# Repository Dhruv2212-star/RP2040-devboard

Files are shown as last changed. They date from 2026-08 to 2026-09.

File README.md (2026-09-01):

# RP2040 based devboard. 
**why did i make this board??**  
hmmmm.. well one day i realised that i have made many projects wit devboard but i have never made my own devboard.  
this was it! so this was a golden project opportunity for me to challenge myself to make something.  
i went and search some tutorials on how devboards worked and how to make them.  
Out of all of the possible devboards out there. one particular board caught my eye, it was the **RP2040** Devboard because it was reallllyy easy to make and really functional and powerful because of it's storage capacity and the no. of GPIO pins it had.  

**Now let me explain to you how i built this devboard :)**  
for a Devboard to work you need to have the basic idea of the chip architecture, with our *RP2040* chip, it uses 3.3v for the main power pins but uses 1.1v for the logic pins and fortunately for our chip it has a built in voltage control which reduces the voltage to 1.1v so no need of extra components  

**decoupling capacitors**- we are using 100nF capacitors per each power pin (IOVDD) and 1uF capacitors for VREG_IN and VREG_OUT each and 2 100nF capacitors for DVDD pin, 100nF capacitor for ADC_AVDD and 100nF for USB VDD  

**Flash storage-** for storing our code in the devboard we are using W25Q128JVS chip for this function, we are going to use QSPI pins for this connection  

**Crystal oscillator**- for this build the data sheet recommends 12Mhz crystal, and in our board we are using   
ABLS-12.000MHZ-B4-T for this  

**GPIO pin extensions**- using 1x20 connectors, we extend it to connectors where we can utilize them.  

# BOM ( Bill of materials)  
## Bill of Materials (BOM)

| Reference | Qty | Value / Part | Footprint | Purchase |
| --- | --: | --- | --- | --- |
| C1, C2 | 2 | 10 µF | `C_0603_1608Metric` | [Link](https://amzn.in/d/0bsal2JG) |
| C3, C4, C5, C9–C15 |  10 | 100 nF | `C_0402_1005Metric` | [Link](https://amzn.in/d/0h4zQ3Lf) |
| C6, C7 | 2 | 1 µF | `C_0402_1005Metric` | [Link](https://amzn.in/d/0exjZiSL) |
| C8 | 1 | 100 nF | `C_0402_1005Metric` | [Link](https://amzn.in/d/0hHEodPN) |
| C16, C17 | 2 | 27 pF | `C_0402_1005Metric` | [Link](https://amzn.in/d/0bekUa1Y) |
| D1 | 1 | LED | `LED_0603_1608Metric` | [Link](https://amzn.in/d/0jdhjUcx) |
| J1 | 1 | USB-C Receptacle USB2.0 16P | `USB_C_Receptacle_GCT_USB4105-xx-A_16P` | [Link](https://amzn.in/d/03EJbP2P) |
| J2 | 1 | 1×2 Pin Header | `PinHeader_1x02_P2.54mm_Vertical` | Cut from 1×40 header |
| J3 | 1 | 1×4 Pin Header | `PinHeader_1x04_P2.54mm_Vertical` | Cut from 1×40 header |
| J4, J5 | 2 | 1×20 Pin Header | `PinHeader_1x20_P2.54mm_Vertical` | [Link](https://amzn.in/d/06pAoX1t) |
| R1, R2 | 2 | 5.1 kΩ | `R_0603_1608Metric` | [Link](https://amzn.in/d/05xfBy6B) |
| R3, R9 | 2 | 10 kΩ | `R_0402_1005Metric` | [Link](https://amzn.in/d/02u6eVpk) |
| R4, R5 | 2 | 27.4 Ω | `R_0603_1608Metric` | [Link](https://amzn.in/d/07J2YWcO) |
| R6, R7, R8 | 3 | 1 kΩ | `R_0603_1608Metric` | [Link](https://amzn.in/d/02u6eVpk) |
| SW1 | 1 | RESET — TL3301AF160QG | `SW_Push_1P1T_NO` | [Link](https://www.digikey.in/short/r89qvhmn) |
| U1 | 1 | NCP1117-3.3 | `TO-252-2` | [Link](https://www.digikey.in/short/ff3dmq3j) |
| U2 | 1 | RP2040 | `QFN-56-1EP_7x7mm` | [Link](https://amzn.in/d/011fsK23) |
| U3 | 1 | W25Q128JVS | `SOIC-8_5.3x5.3mm_P1.27mm` | [Link](https://www.digikey.in/short/zzb4v2bb) |
| Y1 | 1 | Crystal | `Crystal_SMD_HC49-SD` | [Link](https://www.digikey.in/short/9m893pn7) |

# Final schematic look: 



# PCB tracing pics on KIcad  





# Acutual PCB preview 

Thumbnail  

# 3D model view in Kicad 



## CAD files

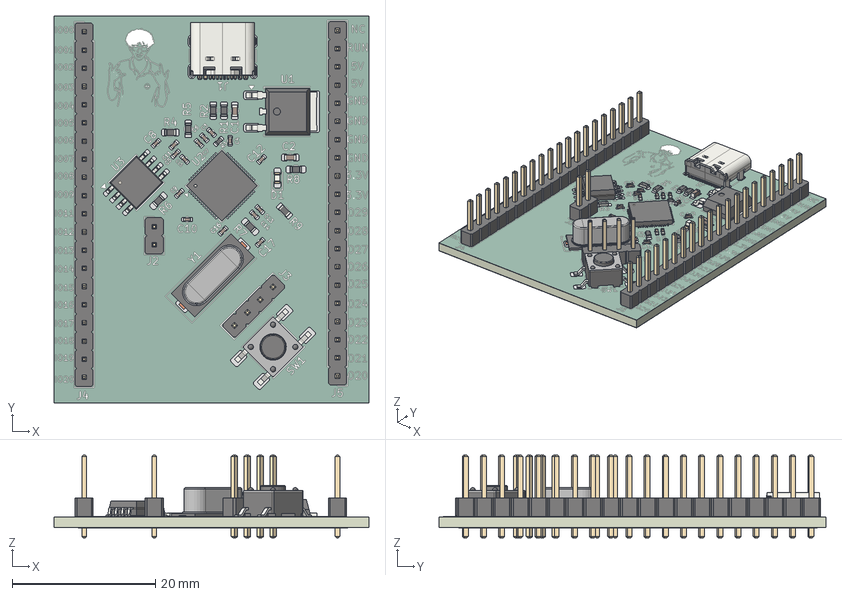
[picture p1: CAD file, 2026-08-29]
3D model/3D Model of PCB.step
44.0 x 54.0 x 11.5 mm
C_0402_1005Metric x 15
SOIC-8_5.3x5.3mm_P1.27mm
R_0603_1608Metric x 8
R_0402_1005Metric
QFN-56-1EP_7x7mm_P0.4mm_EP3.2x3.2mm
LED_0603_1608Metric
932d09b3-9c39-11ed-93f0-dde97e994e83_part
932d09b4-9c39-11ed-93f0-dde97e994e83_part
932d09b5-9c39-11ed-93f0-dde97e994e83_part
Crystal_SMD_HC49-SD
USB_C_Receptacle_16P_TopMnt_Horizontal_GCT_USB4105-xx-A
PinHeader_1x20_P254mm_Vertical x 2
C_0603_1608Metric x 2
PinHeader_1x04_P254mm_Vertical
PinHeader_1x02_P254mm_Vertical
SW_Push_1P1T_NO_E-Switch_TL3301NxxxxxG
RP2040 Devboard_copper
RP2040 Devboard_pad
RP2040 Devboard_via
RP2040 Devboard_silkscreen
RP2040 Devboard_soldermask x 2
RP2040 Devboard_PCB

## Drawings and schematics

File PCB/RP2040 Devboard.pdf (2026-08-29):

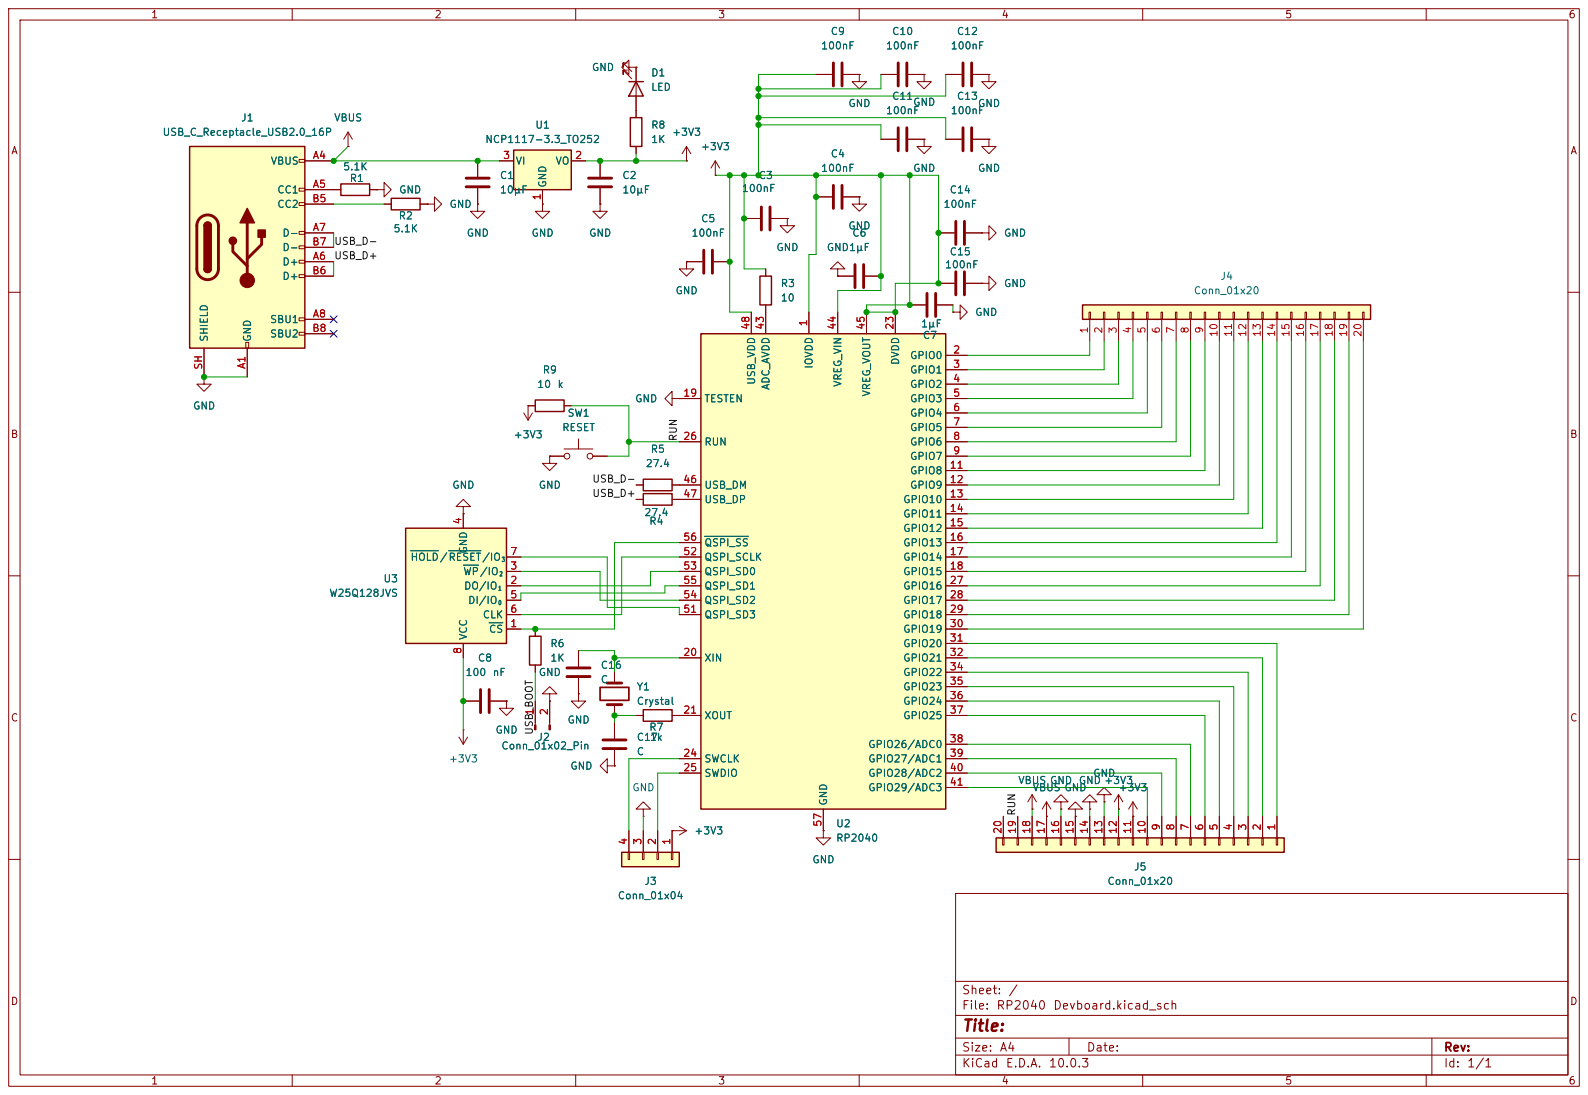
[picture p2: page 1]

Size: A4 | Rev:
KiCad E.D.A. 10.0.3 | Id: 1/1

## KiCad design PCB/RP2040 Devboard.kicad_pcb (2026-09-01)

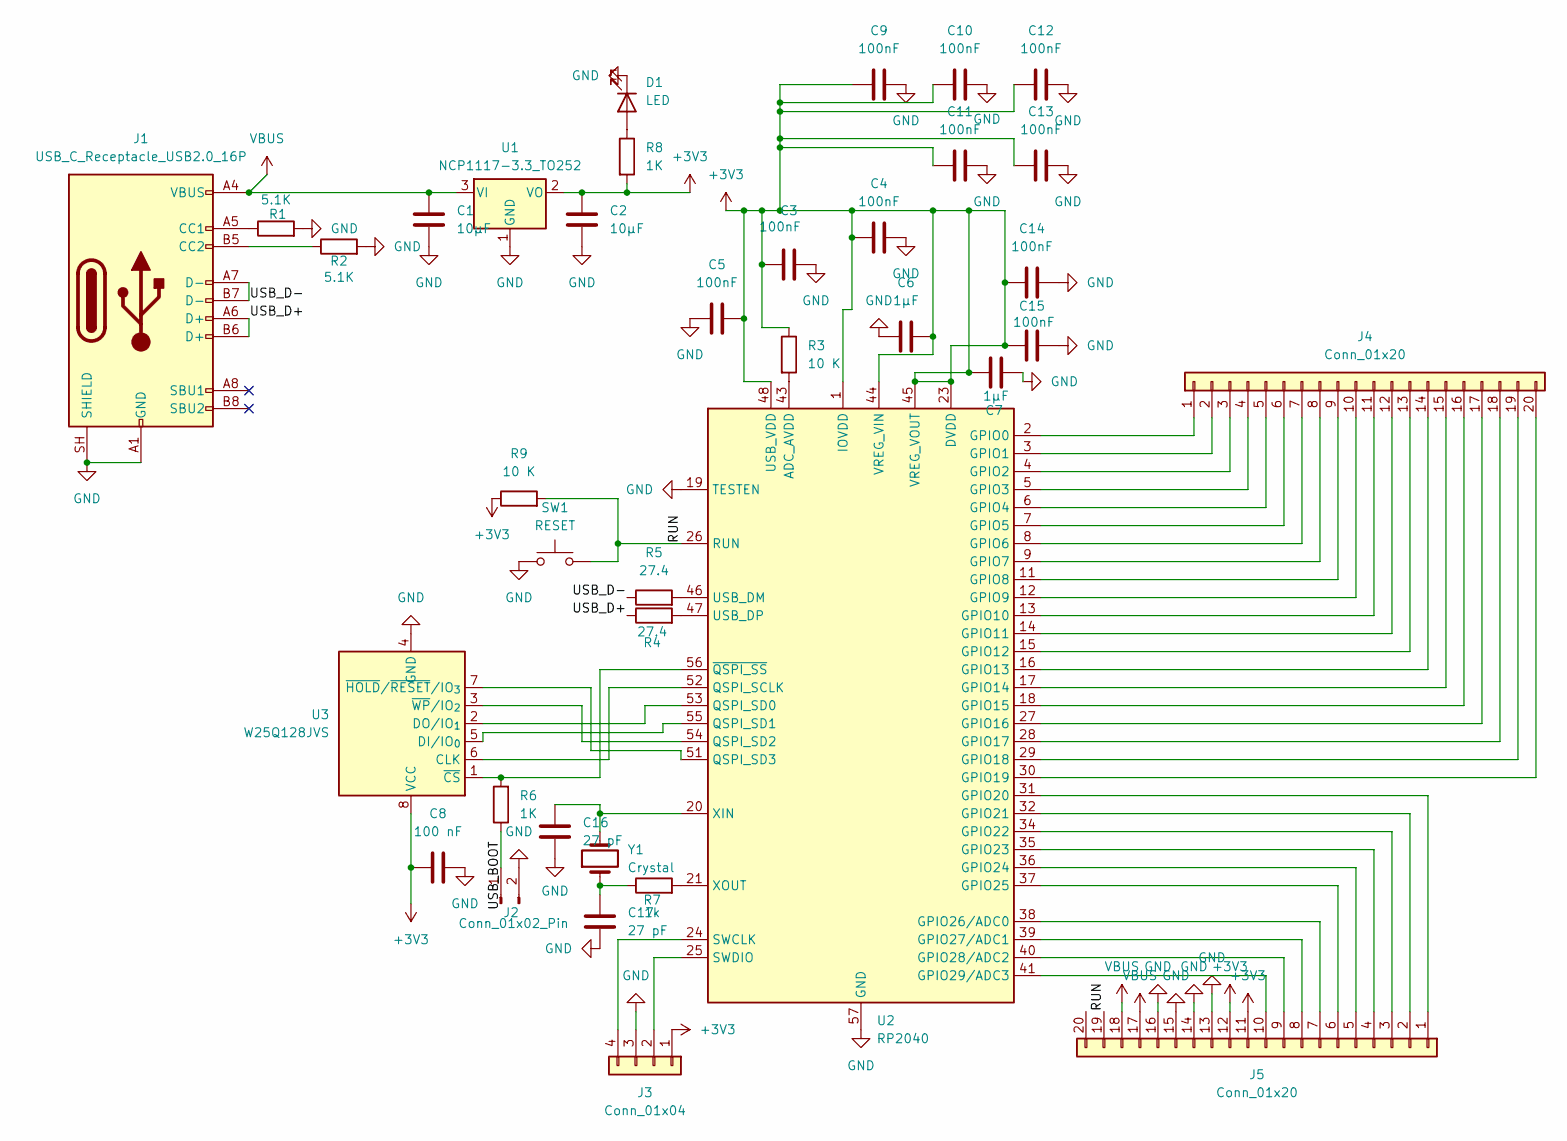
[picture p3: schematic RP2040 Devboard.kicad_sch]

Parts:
C1, C2: 10μF; C_0603_1608Metric
C3, C4, C5, C9, C10, C11, C12, C13, C14, C15: 100nF; C_0402_1005Metric
C6, C7: 1µF; C_0402_1005Metric
C8: 100 nF; C_0402_1005Metric
C16, C17: 27 pF; C_0402_1005Metric
D1: LED; LED_0603_1608Metric_Pad1.05x0.95mm_HandSolder
J1: USB_C_Receptacle_USB2.0_16P; USB_C_Receptacle_GCT_USB4105-xx-A_16P_TopMnt_Horizontal
J2: Conn_01x02_Pin; PinHeader_1x02_P2.54mm_Vertical
J3: Conn_01x04; PinHeader_1x04_P2.54mm_Vertical
J4, J5: Conn_01x20; PinHeader_1x20_P2.54mm_Vertical
R1, R2: 5.1K; R_0603_1608Metric
R3: 10 K; R_0402_1005Metric
R4, R5: 27.4; R_0603_1608Metric
R6, R8: 1K; R_0603_1608Metric_Pad0.98x0.95mm_HandSolder
R7: 1k; R_0603_1608Metric_Pad0.98x0.95mm_HandSolder
R9: 10 K; R_0603_1608Metric
SW1: RESET; SW_Push_1P1T_NO_E-Switch_TL3301NxxxxxG
U1: NCP1117-3.3_TO252; TO-252-2
U2: RP2040; QFN-56-1EP_7x7mm_P0.4mm_EP3.2x3.2mm
U3: W25Q128JVS; SOIC-8_5.3x5.3mm_P1.27mm
Y1: Crystal; Crystal_SMD_HC49-SD

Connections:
+3V3: C2.1, C3.1, C4.2, C5.2, C6.1, C7.2, C8.1, C9.1, C10.1, C11.1, C12.1, C13.1, C14.1, C15.1, J3.1, J5.11, J5.12, R3.1, R8.2, R9.1, U1.2 (VO), U2.1 (IOVDD), U2.10 (IOVDD), U2.22 (IOVDD), U2.23 (DVDD), U2.33 (IOVDD), U2.42 (IOVDD), U2.44 (VREG_VIN), U2.45 (VREG_VOUT), U2.48 (USB_VDD), U2.49 (IOVDD), U2.50 (DVDD), U3.8 (VCC)
/RUN: J5.19, R9.2, SW1.2, U2.26 (RUN)
/USB_BOOT: J2.1, R6.1
/USB_D+: J1.A6 (D+), J1.B6 (D+), R4.1
/USB_D-: J1.A7 (D-), J1.B7 (D-), R5.1
GND: C1.2, C2.2, C3.2, C4.1, C5.1, C6.2, C7.1, C8.2, C9.2, C10.2, C11.2, C12.2, C13.2, C14.2, C15.2, C16.2, C17.2, D1.1 (K), J1.A1 (GND), J1.A12 (GND), J1.B1 (GND), J1.B12 (GND), J1.SH (SHIELD), J2.2, J3.3, J5.13, J5.14, J5.15, J5.16, R1.2, R2.2, SW1.1, U1.1 (GND), U2.19 (TESTEN), U2.57 (GND), U3.4 (GND)
unnamed: C17.1, R7.1, Y1.1
unnamed: D1.2 (A), R8.1
unnamed: J1.A5 (CC1), R1.1
unnamed: J1.B5 (CC2), R2.1
unnamed: J3.2, U2.25 (SWDIO)
unnamed: J3.4, U2.24 (SWCLK)
unnamed: J4.1, U2.2 (GPIO0)
unnamed: J4.2, U2.3 (GPIO1)
unnamed: J4.3, U2.4 (GPIO2)
unnamed: J4.4, U2.5 (GPIO3)
unnamed: J4.5, U2.6 (GPIO4)
unnamed: J4.6, U2.7 (GPIO5)
unnamed: J4.7, U2.8 (GPIO6)
unnamed: J4.8, U2.9 (GPIO7)
unnamed: J4.9, U2.11 (GPIO8)
unnamed: J4.10, U2.12 (GPIO9)
unnamed: J4.11, U2.13 (GPIO10)
unnamed: J4.12, U2.14 (GPIO11)
unnamed: J4.13, U2.15 (GPIO12)
unnamed: J4.14, U2.16 (GPIO13)
unnamed: J4.15, U2.17 (GPIO14)
unnamed: J4.16, U2.18 (GPIO15)
unnamed: J4.17, U2.27 (GPIO16)
unnamed: J4.18, U2.28 (GPIO17)
unnamed: J4.19, U2.29 (GPIO18)
unnamed: J4.20, U2.30 (GPIO19)
unnamed: J5.1, U2.31 (GPIO20)
unnamed: J5.2, U2.32 (GPIO21)
unnamed: J5.3, U2.34 (GPIO22)
unnamed: J5.4, U2.35 (GPIO23)
unnamed: J5.5, U2.36 (GPIO24)
unnamed: J5.6, U2.37 (GPIO25)
unnamed: J5.7, U2.38 (GPIO26/ADC0)
unnamed: J5.8, U2.39 (GPIO27/ADC1)
unnamed: J5.9, U2.40 (GPIO28/ADC2)
unnamed: J5.10, U2.41 (GPIO29/ADC3)
unnamed: R3.2, U2.43 (ADC_AVDD)
unnamed: U2.52 (QSPI_SCLK), U3.6 (CLK)
unnamed: U2.53 (QSPI_SD0), U3.2 (DO/IO_{1})
unnamed: U2.55 (QSPI_SD1), U3.5 (DI/IO_{0})
unnamed: U2.54 (QSPI_SD2), U3.3 (~WP/IO_{2})
unnamed: U2.51 (QSPI_SD3), U3.7 (~HOLD/~RESET/IO_{3})
unnamed: R5.2, U2.46 (USB_DM)
unnamed: R4.2, U2.47 (USB_DP)
unnamed: C16.1, U2.20 (XIN), Y1.2
unnamed: R7.2, U2.21 (XOUT)
unnamed: R6.2, U2.56 (~QSPI_SS), U3.1 (~CS)
VBUS: C1.1, J1.A4 (VBUS), J1.A9 (VBUS), J1.B4 (VBUS), J1.B9 (VBUS), J5.17, J5.18, U1.3 (VI)

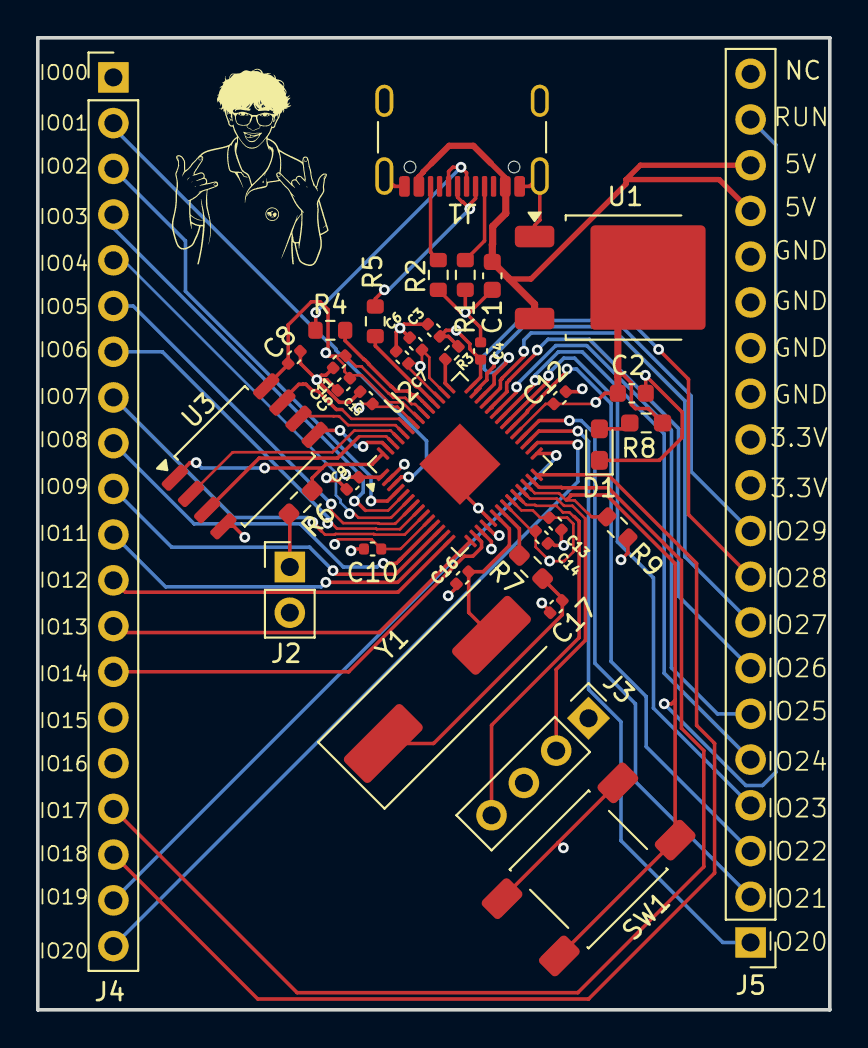
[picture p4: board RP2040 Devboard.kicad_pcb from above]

Board: 4 copper layers, 44.0 x 54.0 mm, 37 parts (0 on the bottom side), 54 nets.

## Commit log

2026-08-29 Development files
    [3D Model of PCB.step, BOM.csv, RP2040 Devboard.kicad_pcb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]
2026-08-29 3D view of PCB
2026-09-01 BOM added
2026-09-01 newer ver. of gerber file
    [BOM.csv, RP2040 Devboard.kicad_pcb, RP2040 Devboard.kicad_sch]
